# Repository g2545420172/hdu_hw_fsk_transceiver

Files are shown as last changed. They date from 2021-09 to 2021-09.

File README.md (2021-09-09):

# hdu_hw_fsk_transceiver
杭电2021秋季短学期 通信系统课程设计 基于 FSK 调制的 PC 机通信电路设计 
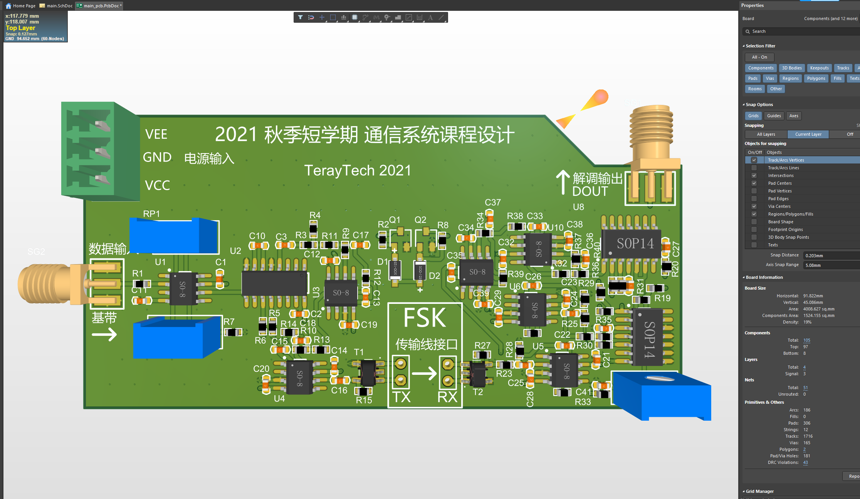
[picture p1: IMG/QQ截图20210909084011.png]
 
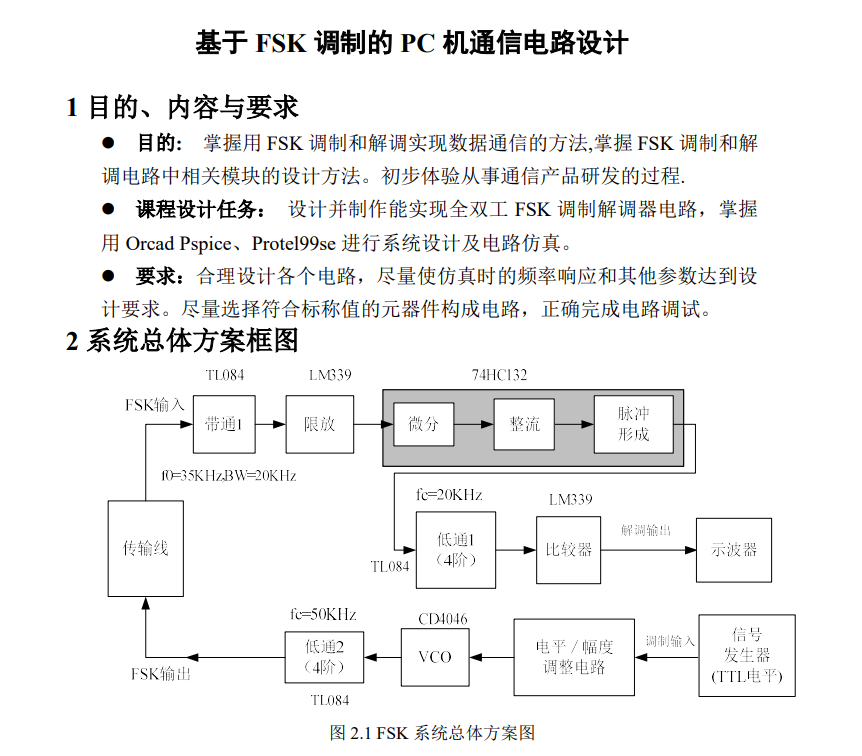
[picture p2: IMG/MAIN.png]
main
 
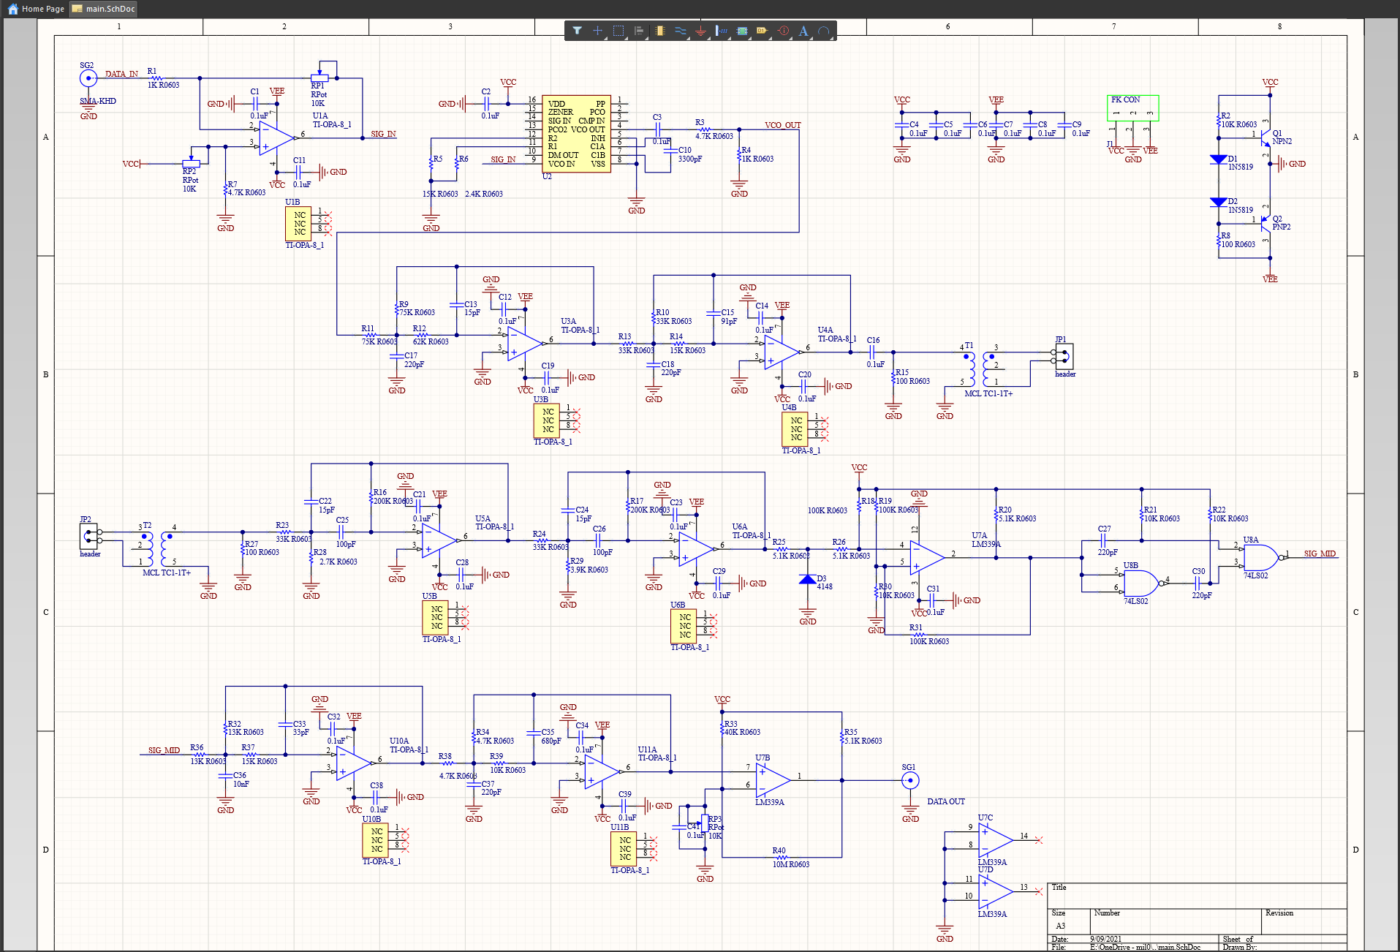
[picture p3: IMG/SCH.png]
sch
 
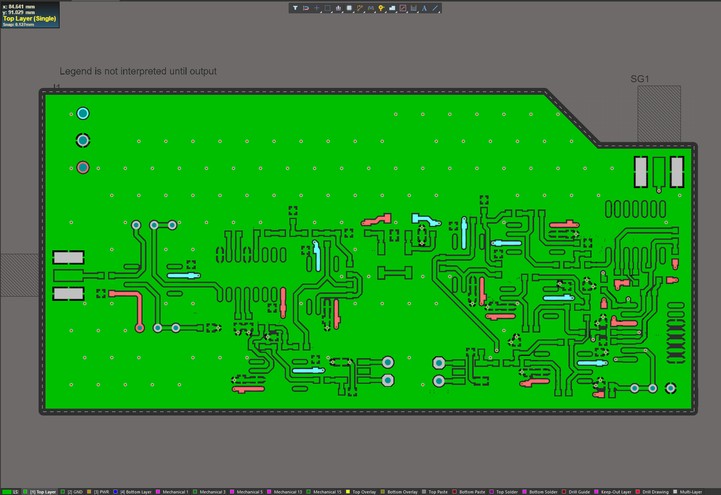
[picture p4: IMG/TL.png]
TL
 
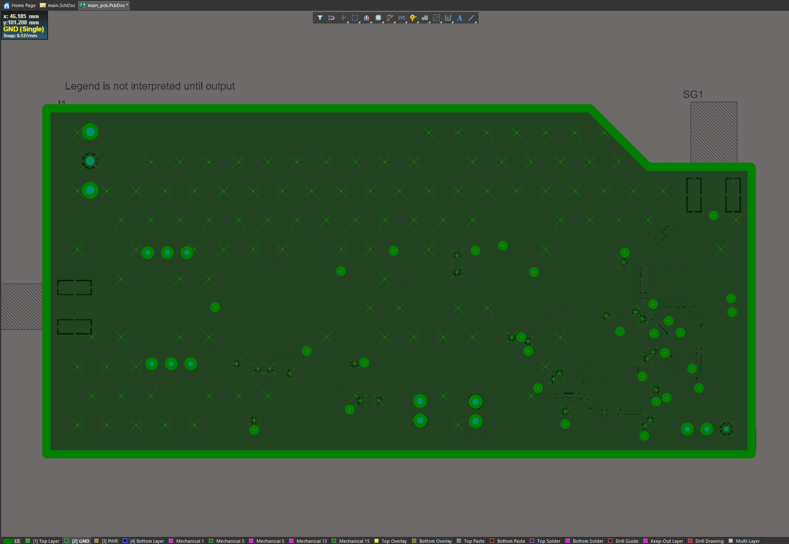
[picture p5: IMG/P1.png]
P1
 
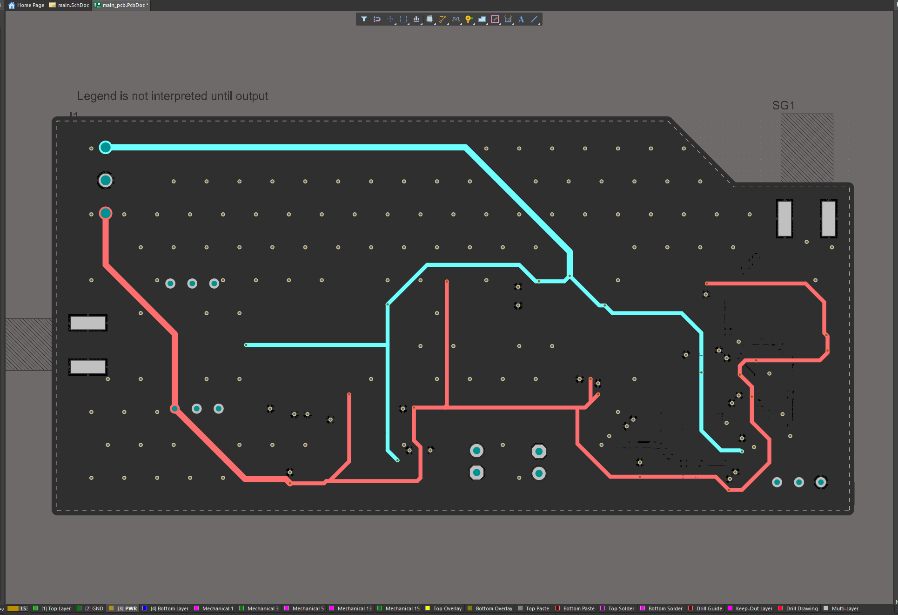
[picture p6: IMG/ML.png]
ML
 
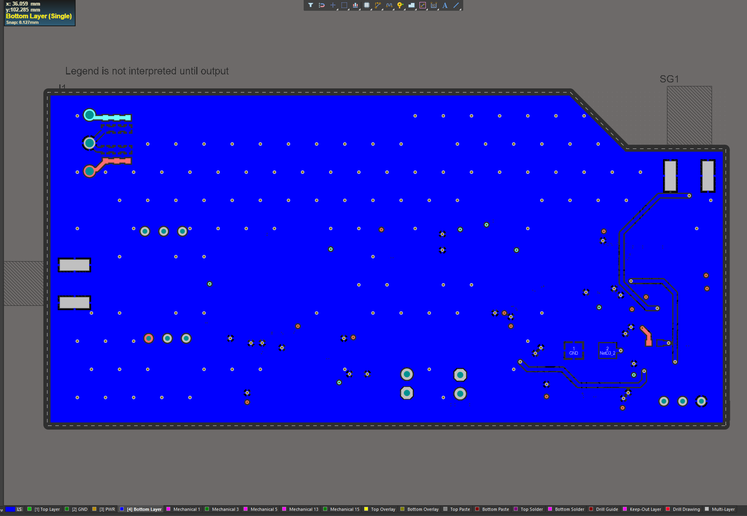
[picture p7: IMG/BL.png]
BL


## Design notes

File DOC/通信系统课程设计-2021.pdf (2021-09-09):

# 通信系统课程设计

## 栾慎吉 刘超

## 杭州电子科技大学

## 信息工程学院

2

3

## 基于 FSK 调制的 PC 机通信电路设计

## 1 目的、内容与要求

- 目的: 掌握用 FSK 调制和解调实现数据通信的方法,掌握 FSK 调制和解 调电路中相关模块的设计方法。初步体验从事通信产品研发的过程. 课程设计任务： 设计并制作能实现全双工 FSK 调制解调器电路，掌握

用 Orcad Pspice、Protel99se 进行系统设计及电路仿真。
- 要求：合理设计各个电路，尽量使仿真时的频率响应和其他参数达到设 计要求。尽量选择符合标称值的元器件构成电路，正确完成电路调试。

## 2 系统总体方案框图

图 2.1 FSK 系统总体方案图
- 信号调制过程如下：
调制数据由信号发生器产生（电平为 TTL，波特率不超过 9600Baud），送入 电平/幅度调整电路完成电平的变换，再经过锁相环（CD4046）,产生两个频率信 号分别为 30kHz 和 40kHz（发“1”时产生 30kHz 方波，发“0”时产生 40kHz 方波）， 再经过低通滤波器 2，变成平滑的正弦波，最后通过线圈实现单端到差分信号的 转换。
- 信号的解调过程如下：
首先经过带通滤波器 1，滤除带外噪声，实现信号的提取。在本设计中 FSK 信号的解调方式是过零检测法。所以还要经过比较器使正弦信号变成方波，再经 过微分、整流电路和低通滤波器 1 实现信号的解调，最后经过比较器使解调信号 成为 TTL 电平。在示波器上会看到接收数据和发送数据是一致的。
- 各主要电路模块作用：

4

电平/幅度调整电路：完成 TTL 电平到 VCO 控制电压的调整； VCO 电路：在控制电压作用下，产生 30KHz 和 40KHz 方波； 低通 2：把 30KHz、40KHz 方波滤成正弦波； 线圈：完成单端信号和差分信号的相互转换；
带通 1：对带外信号抑制，完成带内信号的提取；
限放电路：正弦波整形成方波，同时保留了过零点的信息； 微分、整流、脉冲形成电路：完成信号过零点的提取；
低通 1：提取基带信号，实现初步解调；
比较器：把初步解调后的信号转换成 TTL 电平；

## 3 系统设计技术要求

(1)FSK 解调方案：过零检测法
(2)信道复用方式：频分复用，全双工通信
(3)频率分配：f=35±5KHz， "1"--30KHz, "0"--40KHz (4)系统工作最高码元速率：RB=9600Baud
(5)线路阻抗：100 欧姆
(6)信号接收灵敏度：优于 10mv
(7)信号发送电平：1Vpp

图 3.1 FSK 信号的频谱

## 4 主要器件型号的选择及功能

74HC132：四 2 输入与非施密特触发器（用作过零检测电路） LM339：4 比较器（用作限放和比较器）
CD4046：COMS 锁相环（用作 VCO）
TL084：运算放大器（用作滤波器和电平／幅度调整电路用）

## 5 系统中各种滤波器设计要求

(1)带通 1 滤波器设计指标：
通带：26KHz-46KHz，通带波动 3dB；
阻带截止频率：fc＝75KHz 时，要求衰减大于 10dB；

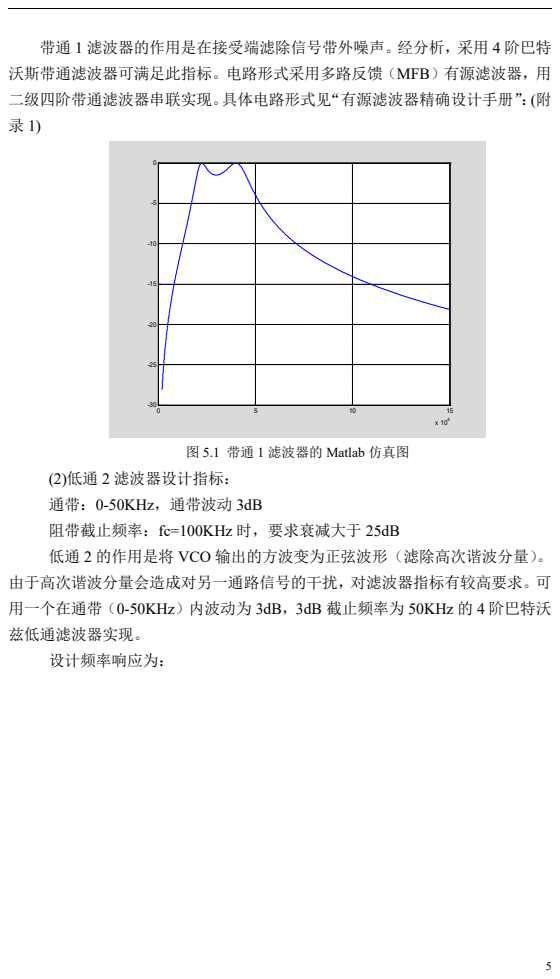
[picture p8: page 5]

带通 1 滤波器的作用是在接受端滤除信号带外噪声。经分析，采用 4 阶巴特
沃斯带通滤波器可满足此指标。电路形式采用多路反馈（MFB）有源滤波器，用
二级四阶带通滤波器串联实现。具体电路形式见“有源滤波器精确设计手册”：(附

图 5.1 带通 1 滤波器的 Matlab 仿真图

(2)低通 2 滤波器设计指标：
通带：0-50KHz，通带波动 3dB
阻带截止频率：fc=100KHz 时，要求衰减大于 25dB
低通 2 的作用是将 VCO 输出的方波变为正弦波形（滤除高次谐波分量）。
由于高次谐波分量会造成对另一通路信号的干扰，对滤波器指标有较高要求。可
用一个在通带（0-50KHz）内波动为 3dB，3dB 截止频率为 50KHz 的 4 阶巴特沃
兹低通滤波器实现。
设计频率响应为：

6

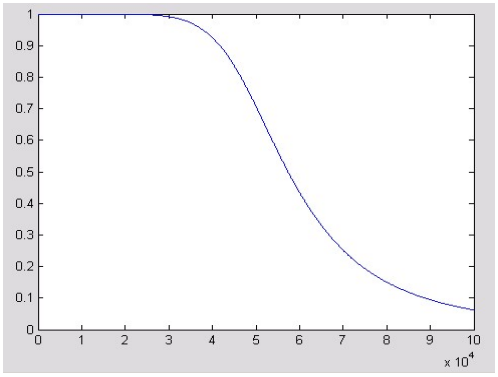
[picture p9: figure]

图 5.2 低通 2 滤波器的 Matlab 仿真图 (3)低通 1 指标：
通带：0-20KHz，通带波动 3dB；
阻带截止频率：fc＝30KHz 时，要求衰减大于 10dB；

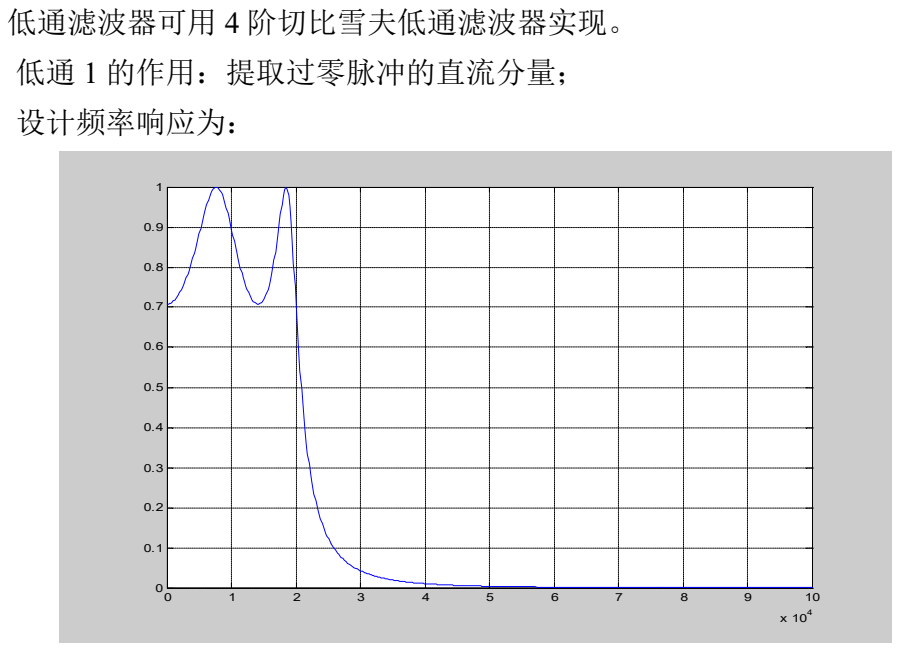
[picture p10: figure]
低通滤波器可用 4 阶切比雪夫低通滤波器实现。; 低通 1 的作用：提取过零脉冲的直流分量；; 设计频率响应为：

图 5.3 低通 1 滤波器的 Matlab 仿真图

## 6 系统中各部分模块参考电路

(1)带通 1(4 阶带通)-- 接收滤波器原理图及仿真图 要求通带：26KHz—46KHz，通带波动 3dB；阻带截止频率：fc＝75KHz 时，

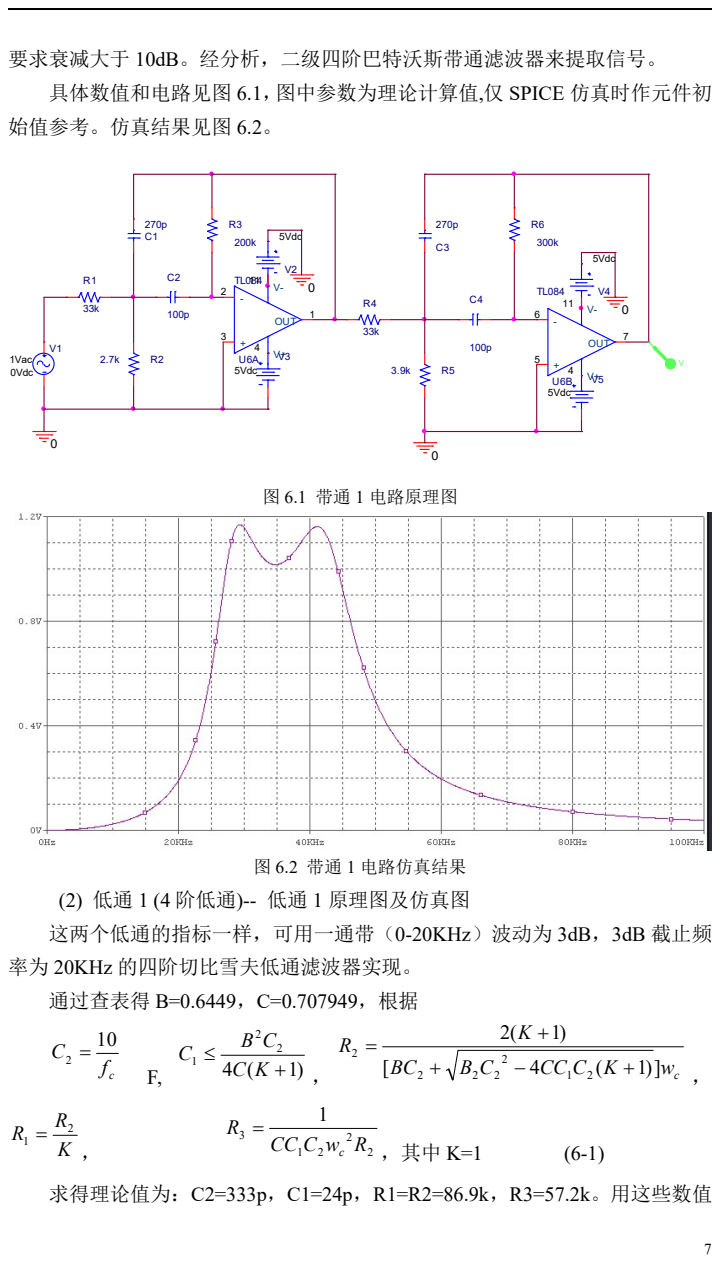
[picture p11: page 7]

要求衰减大于 10dB。经分析，二级四阶巴特沃斯带通滤波器来提取信号。
具体数值和电路见图 6.1，图中参数为理论计算值,仅 SPICE 仿真时作元件初
始值参考。仿真结果见图 6.2。 R1

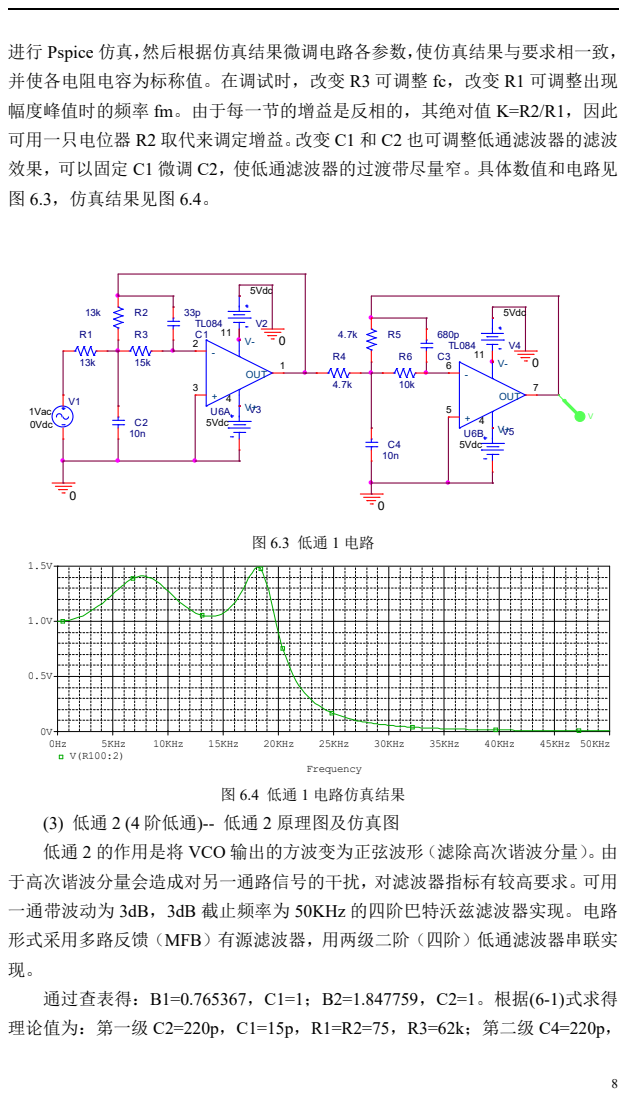
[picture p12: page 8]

进行 Pspice 仿真，然后根据仿真结果微调电路各参数，使仿真结果与要求相一致，
并使各电阻电容为标称值。在调试时，改变 R3 可调整 fc，改变 R1 可调整出现
幅度峰值时的频率 fm。由于每一节的增益是反相的，其绝对值 K=R2/R1，因此
可用一只电位器 R2 取代来调定增益。改变 C1 和 C2 也可调整低通滤波器的滤波
效果，可以固定 C1 微调 C2，使低通滤波器的过渡带尽量窄。具体数值和电路见
图 6.3，仿真结果见图 6.4。 R1

(3) 低通 2 (4 阶低通)-- 低通 2 原理图及仿真图
低通 2 的作用是将 VCO 输出的方波变为正弦波形（滤除高次谐波分量）。由
于高次谐波分量会造成对另一通路信号的干扰，对滤波器指标有较高要求。可用
一通带波动为 3dB，3dB 截止频率为 50KHz 的四阶巴特沃兹滤波器实现。电路
形式采用多路反馈（MFB）有源滤波器，用两级二阶（四阶）低通滤波器串联实
通过查表得：B1=0.765367，C1=1；B2=1.847759，C2=1。根据(6-1)式求得
理论值为：第一级 C2=220p，C1=15p，R1=R2=75，R3=62k；第二级 C4=220p，

6.6。 V1

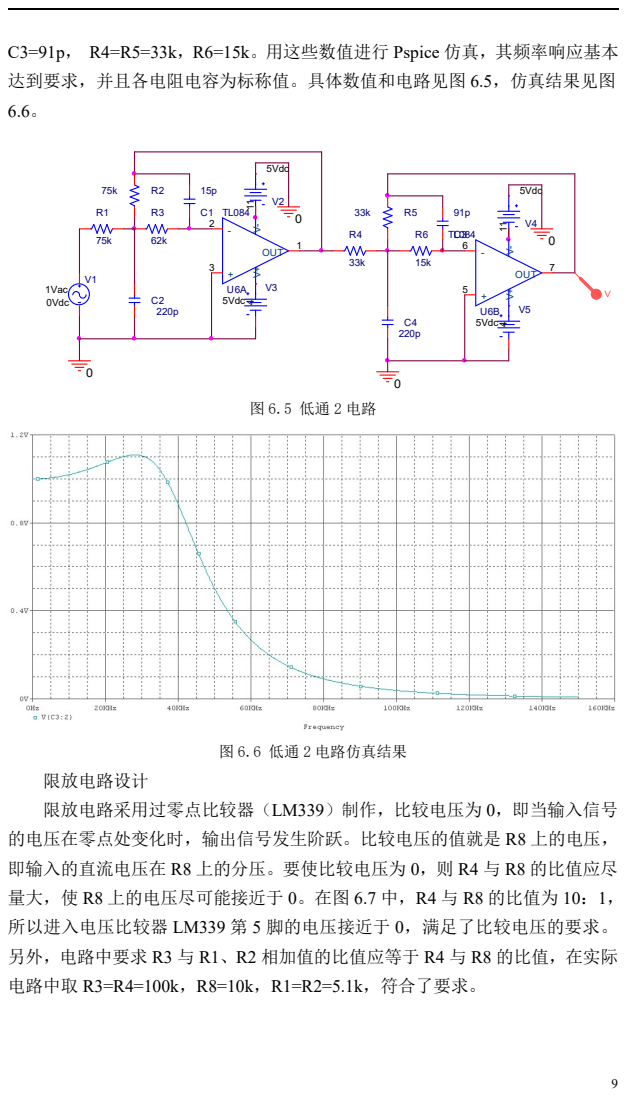
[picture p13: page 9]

C3=91p， R4=R5=33k，R6=15k。用这些数值进行 Pspice 仿真，其频率响应基本
达到要求，并且各电阻电容为标称值。具体数值和电路见图 6.5，仿真结果见图

限放电路设计
限放电路采用过零点比较器（LM339）制作，比较电压为 0，即当输入信号
的电压在零点处变化时，输出信号发生阶跃。比较电压的值就是 R8 上的电压，
即输入的直流电压在 R8 上的分压。要使比较电压为 0，则 R4 与 R8 的比值应尽
量大，使 R8 上的电压尽可能接近于 0。在图 6.7 中，R4 与 R8 的比值为 10：1，
所以进入电压比较器 LM339 第 5 脚的电压接近于 0，满足了比较电压的要求。
另外，电路中要求 R3 与 R1、R2 相加值的比值应等于 R4 与 R8 的比值，在实际
电路中取 R3=R4=100k，R8=10k，R1=R2=5.1k，符合了要求。

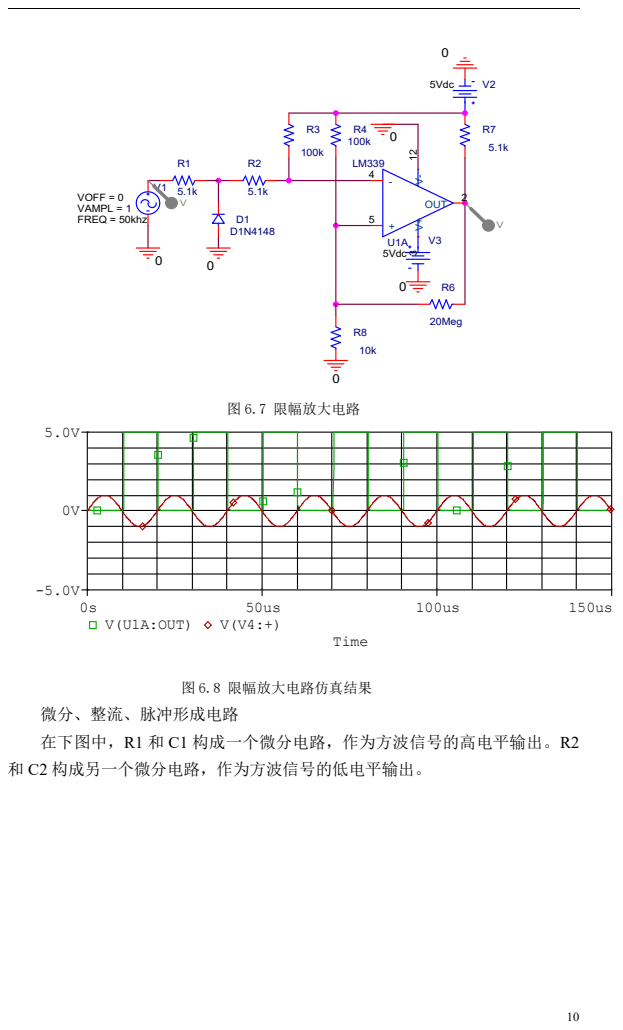
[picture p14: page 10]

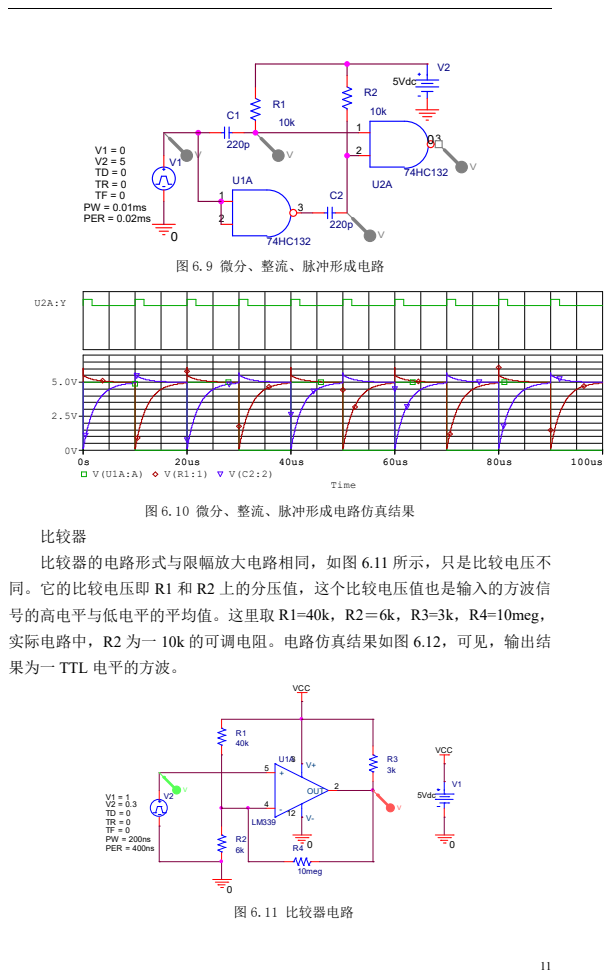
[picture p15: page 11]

比较器
比较器的电路形式与限幅放大电路相同，如图 6.11 所示，只是比较电压不
同。它的比较电压即 R1 和 R2 上的分压值，这个比较电压值也是输入的方波信
号的高电平与低电平的平均值。这里取 R1=40k，R2＝6k，R3=3k，R4=10meg，
实际电路中，R2 为一 10k 的可调电阻。电路仿真结果如图 6.12，可见，输出结
果为一 TTL 电平的方波。

12

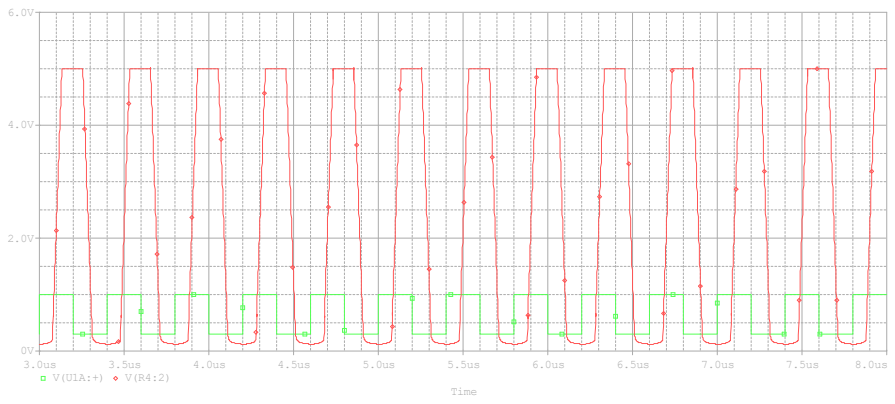
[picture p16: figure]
Time

图 6.12 比较器电路仿真结果
电平/幅度调整电路
电平/幅度调整电路如图 6.13，根据 VCO 电路的实际调试结果得出与各频率 相对应的输入电压即电平/幅度调整电路的输出电压，并据此进行 Pspice 仿真。

1

1 1

1

1
0 1

( )
R

V R Rf ViRf Rf
R

Vi V
V V

在实际电路中 R1＝75k，Rf 是一阻值为 10k 的可调电阻，所以调整 Rf 可以 改变输出 Vo 的大小，若减小 Rf，则 Vo 增大；若增大 Rf，则 Vo 减小，据此进 行电路调整，使输出符合要求。而电阻 R2、R3 的分压值决定了输出 Vo 的中心 电平，在实际电路中，R2 为一阻值为 10k 的可调电阻，改变 R2，可以调整输出 Vo 的中心电平，使输出满足要求。
中心频率 fo=35kHz 时对应的电压为 1.9V，f=30kHz 对应的电压为 1.74V， f=40kHz 对应的电压为 2.08V，这就是电路输出的直流电压分量和方波信号的电

压范围。其中直流电压就是 TL084 第 3 脚输入的电压 V1，即 5V 的电源电压在 R3 上的分压。按比例计算得 R2、R3 的值。输出的方波信号的电压 Vo 由 R2、 Rf 来调节，使之高低电平分别为 1.74V 和 2.08V，在 Pspice 仿真中使用参数扫描，

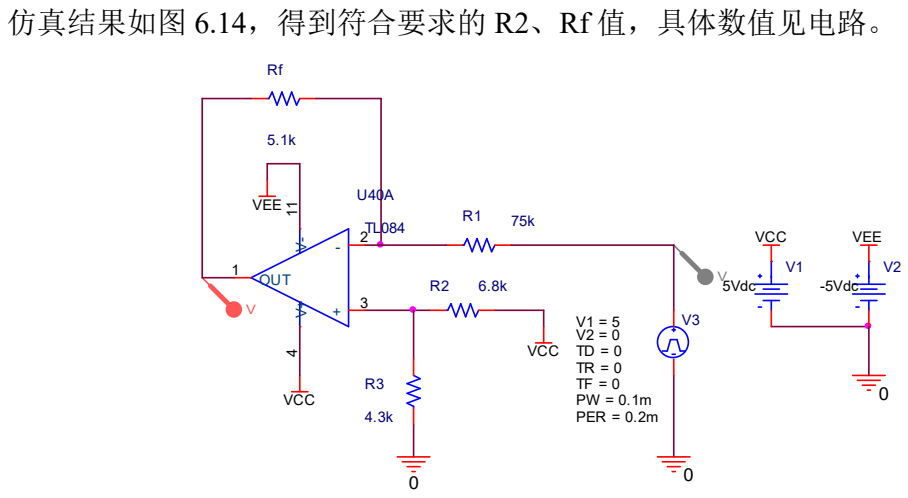
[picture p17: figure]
仿真结果如图 6.14，得到符合要求的 R2、Rf 值，具体数值见电路。; Rf 5.1kVCC; 75kVCC; 5Vdc 0V3 TD = 0 TF = 0 PW = 0.1m; PER = 0.2m; -5Vdc R3; VCC; 6.8k VEE; VEE U40A; - V⁺ V⁻ OUT

13

图 6.13 电平/幅度调整电路

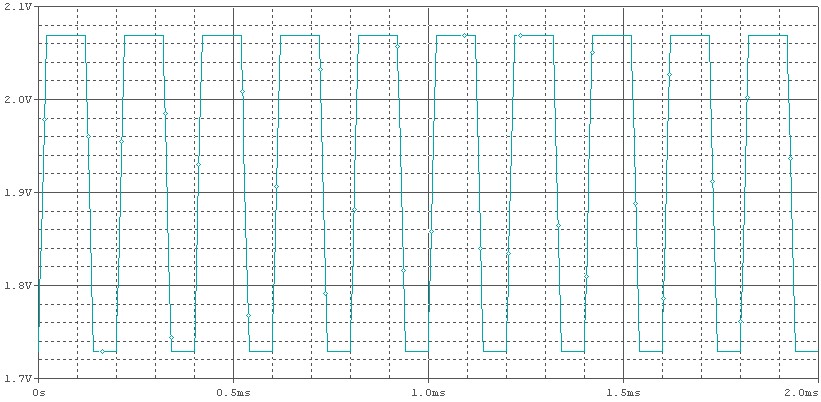
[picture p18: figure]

图 6.14 电平/幅度调整电路仿真结果

### - VCO 电路

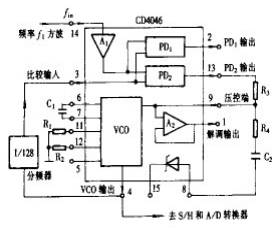
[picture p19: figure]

图 6.15 VCO 电路管脚图
CD4046 锁相环结构如图 6.15，采用的是 RC 型压控振荡器，必须外接电容 C1（接在 6 脚与 7 脚之间）和电阻 R1 作为充放电元件。由于 PLL 对跟踪的输入 信号的频率宽度有要求，所以还需要外接电阻 R2。由于 VCO 是一个电流控制振 荡器，对定时电容 C1 的充电电流与从 9 脚输入的控制电压成正比，使 VCO 的 振荡频率亦正比于该控制电压。当 VCO 控制电压为 0 时，其输出频率最低；当 输入控制电压等于电源电压 VDD 时，输出频率则线性地增大到最高输出频率。 VCO 的工作频率是由 9 管脚上的电压以及 6 和 7 管脚上的电容和 R1、R2 的阻 值确定的。R1 确定最高频率，R2 确定最低工作频率。由于它的充电和放电都由 同一个电容 C1 完成，所以输出的波形是对称方波。
利用 CD4046 的 VCO 可组成一个 V—F（电压—频率）转换器，当其 9 脚输 入的电压从 Vss 变化到 Vdd 时，从 4 脚输出的振荡方波信号的频率成线性变化。

14

变化的频率范围依外接 C1、R1 和 R2 值的不同而异。在 Fmax 和 Fmin 的比值较 小的情况下，R2/R1 可看做与 Fmax/Fmin 成线性关系。
当 Fmin=30kHz，Fmax=40kHz 时，计算得 R1=2.4k，R2=15k，C1=3300p， 在实际的电路板上进行调试，发现中心频率 fo=35kHz 时对应的电压为 1.9V， f=30kHz 对应的电压为 1.74V，f=40kHz 对应的电压为 2.08V，这就是电平/幅度

调整电路所输出的直流电压和方波信号的电压范围。

## 7 系统中电路原理图及 PCB 说明

本系统的电路原理图如图 7.1 所示，由以下几部分组成：电源电路、FSK 调 制电路及 FSK 解调电路组成。相应的 PCB 如图 7.2，该版图的尺寸是 7cm×8cm， 为双面版。版图的尺寸应尽量小，以减少制版费用。按照这个尺寸在 KeepOutLayer 层先画出 PCB 的边界，然后进行元器件的布局、调整，合理的布局能够带来良 好的布线效果。

15

16

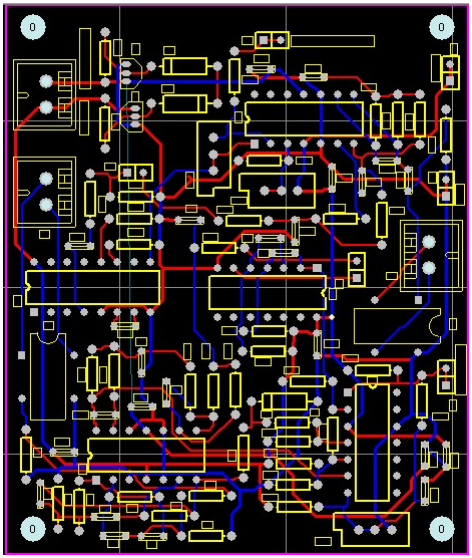
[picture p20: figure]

图 7.2 系统 PCB 版图

17

该设计的材料清单（一份）如下：
元件值 | 名称 | 封装
0.1u(8 个) | C19 | capnew
0.1u | C18 | capnew
0.1u | C20 | capnew
0.1u | C22 | capnew
0.1u | C21 | capnew
0.1u | C17 | capnew
0.1u | C16 | capnew
0.1u | C14 | capnew
1k | R41 | AXIAL0.3
2.4k | R42 | AXIAL0.3
2.7k | R7 | AXIAL0.3
3.9k | R9 | AXIAL0.3
3k | R35 | AXIAL0.3
4.7k(4 个) | R28 | AXIAL0.3
4.7k | R31 | AXIAL0.3
4.7k | R29 | AXIAL0.3
4.7k | R30 | AXIAL0.3
5.1k(3 个) | R13 | AXIAL0.3
5.1k | R11 | AXIAL0.3
5.1k | R12 | AXIAL0.3
10Meg | R34 | AXIAL0.3
10k(6 个) | R19 | AXIAL0.3
10k | R18 | AXIAL0.3
10k | R16 | AXIAL0.3
10k | R17 | AXIAL0.3
10k | R20 | AXIAL0.3
10k | R21 | AXIAL0.3
10k(可调变阻器，3 个) | R40 | VR5
10k | R39 | VR5
10k | R32 | VR5
10n(2 个) | C10 | capnew
10n | C11 | capnew
13k(2 个) | R23 | AXIAL0.3
13k | R24 | AXIAL0.3
15k(3 个) | R27 | AXIAL0.3
15k | R25 | AXIAL0.3
15k | R26 | AXIAL0.3
15p | C23 | capnew
20Meg | R22 | AXIAL0.3
33k(4 个) | R3 | AXIAL0.3
33k | R6 | AXIAL0.3
33k | R4 | AXIAL0.3
33k | R5 | AXIAL0.3
33p | C12 | capnew
40k | R33 | AXIAL0.3
62k | R43 | AXIAL0.3

18

75k(3 个) | R36 | AXIAL0.3
75k | R37 | AXIAL0.3
75k | R38 | AXIAL0.3
91p | C24 | capnew
100(2 个) | R1 | AXIAL0.3
100 | R2 | AXIAL0.3
100k(2 个) | R15 | AXIAL0.3
100k | R14 | AXIAL0.3
100p(3 个) | C4 | capnew
100p | C3 | capnew
100p | C5 | capnew
200k | R8 | AXIAL0.3
220p(4 个) | C8 | capnew
220p | C9 | capnew
220p | C6 | capnew
220p | C7 | capnew
270p(2 个) | C1 | capnew
270p | C2 | capnew
300k | R10 | AXIAL0.3
680p | C13 | capnew
3300p | C15 | capnew
9012 | Q2 | TO-92B
9013 | Q1 | TO-92B
DIODE | D2 | DIODE0.4
DIODE | D1 | DIODE0.4
DIODE | D3 | DIODE0.4
TRANS1 | T1 | t
TRANS1 | T2 | t
芯片 | 总个数
TL084 | 2 只
LM339 | 1 只
74HC132 | 1 只
CD4046 | 1 只
插件名称及个数 | 封装
J1、J2、J3(共 3 只) | MT6CON2 V
U5 | DIP16
U1、U2、U3 和 U4(共 4 只) | DIP14
s1、s2、s3、s4、s5 和 s6 (共 6 只) | SIP2

19

### 实验报告要求

一、 目的、内容与要求

二、 总体方案设计

三、 单元电路设计原理、计算机仿真分析

四、 总结(仿真遇到的问题、解决方法及心得体会)

20

# OrCAD/PSPICE 使用简介

## 杭州电子科技大学

## 信息工程学院

2021 年

# Orcad/Pspice 电路分析步骤

## 1. 启动 Capture CIS：

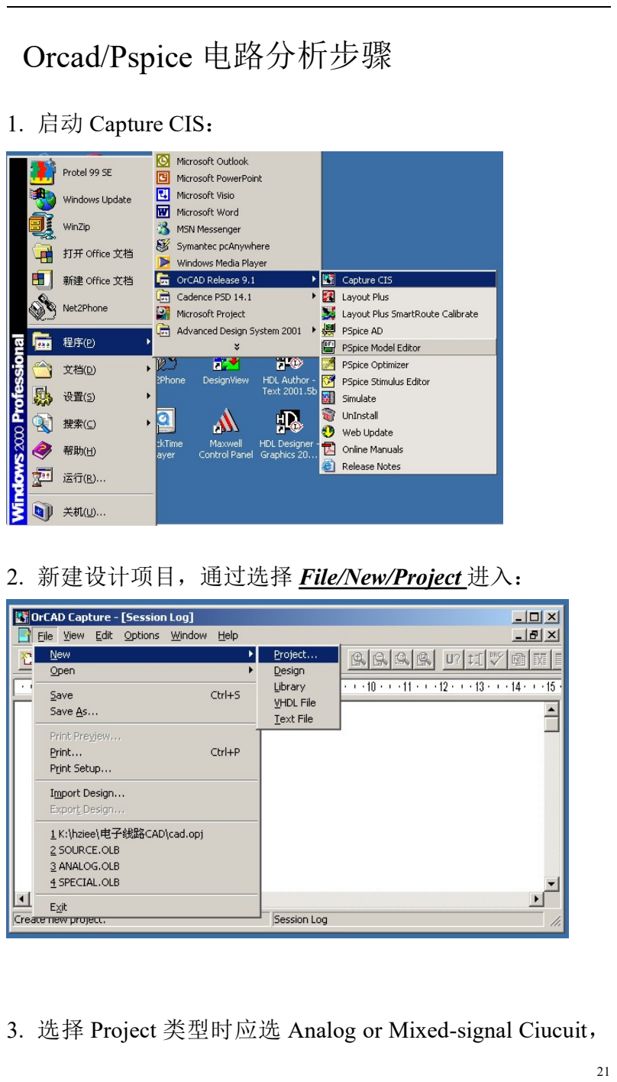
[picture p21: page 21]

21

## 2. 新建设计项目，通过选择 File/New/Project 进入：

## 3. 选择 Project 类型时应选 Analog or Mixed-signal Ciucuit，

## 并确定文件名和存盘路径：

22

## 4. 选择必要的元器件库（以后也可添加）：

## 5. 选完成进入设计窗口：

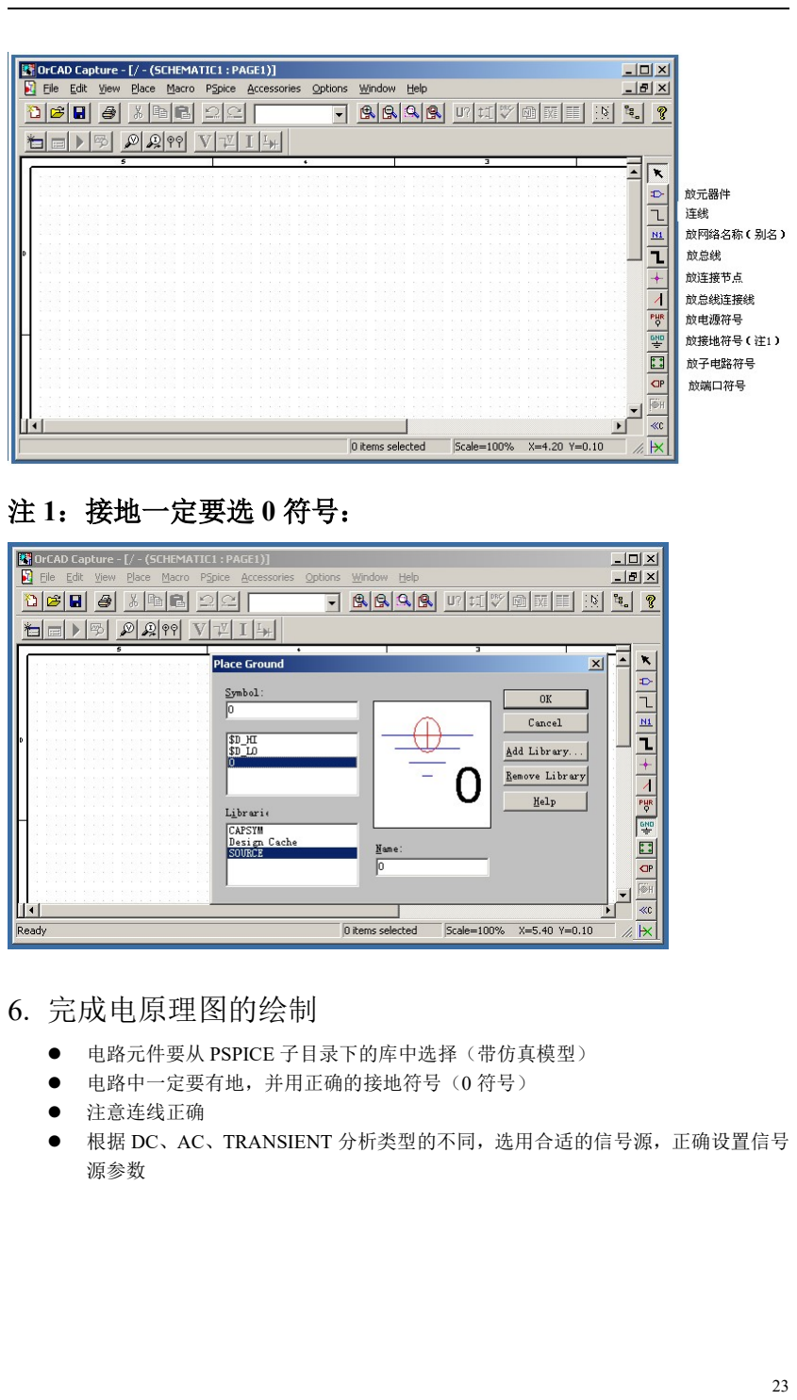
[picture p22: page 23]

23

### 注 1：接地一定要选 0 符号：

## 6. 完成电原理图的绘制

- 电路元件要从 PSPICE 子目录下的库中选择（带仿真模型）
- 电路中一定要有地，并用正确的接地符号（0 符号）
- 注意连线正确
- 根据 DC、AC、TRANSIENT 分析类型的不同，选用合适的信号源，正确设置信号 源参数

24

## 7. 在PSPICE菜单下新建或编辑 Simulation Profile(模拟模式

## 文件) 文件：

## 8. 设置 Simulation Profile 文件参数

25

- 选择分析类型：
- 对选定的分析类型设置正确的参数
对瞬态分析要选择合适的分析时间和最大步长（Maximun step）。对脉冲、正弦等 具有周期性质的信号而言，最大分析步长可取周期的 1/10-1/5。 AC 分析可附带进行噪声分析，Time Domain 分析可附带进行傅里叶分析（谐波失

真分析）

## 9. 选 PSPICE 菜单中的 RUN 或快捷工具条进行电路分析

## 10.观测模拟结果

26

- 增加曲线：Trace/Add Trace
- 显示光标、极值等搜索功能
- 可将曲线拷入剪贴板中，供嵌入 word 等文档使用

27

# Orcad/Pspice 电路分析上机练习题

## 练习题

### 1. 二极管伏安特性分析（DC 扫描分析，单参数扫描）

0

V1
0.5Vdc

I D1

D1N4148

注：二极管在 Diode 库中，电压源在 SOURCE 库中
参考参数设置：

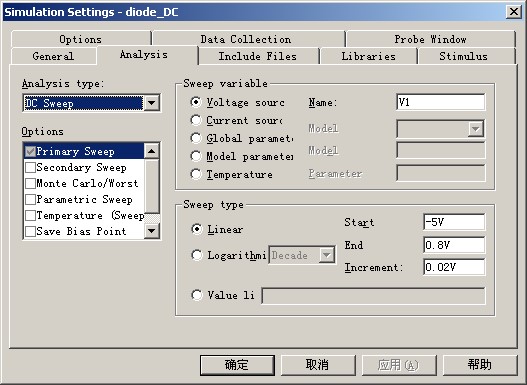
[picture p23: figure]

参考分析结果：

28

### 2. 三极管共射输出特性曲线分析（DC 扫描分析，双扫描参数）

I1

1mAdc

Q2

Q2N2220

0

V1
12Vdc

注：三极管在 Bipolar 库中，电压源、电流源在 SOURCE 库中

### 参考参数设置：

主扫描参数：

参变量参数设置：

分析结果：

29

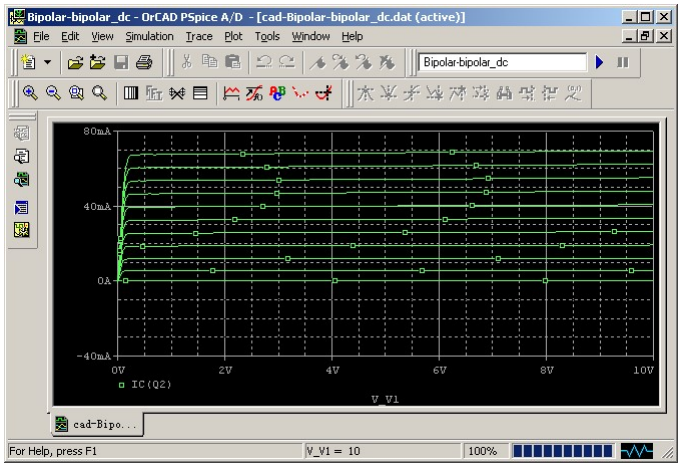
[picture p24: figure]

### 3. 如下电路，试计如所示的电路在（0℃）到 40℃时的直流工作点 IBQ、VBEQ、ICQ 随温

度升变化时的工作点变化曲线。

提示：
参数设置如下：

0

0

VCC

R2
4.6K

12Vdc V1 VCC
R1
73K

Q1

Q2N2222

R3
2k

30

## 练习题（AC 分析）

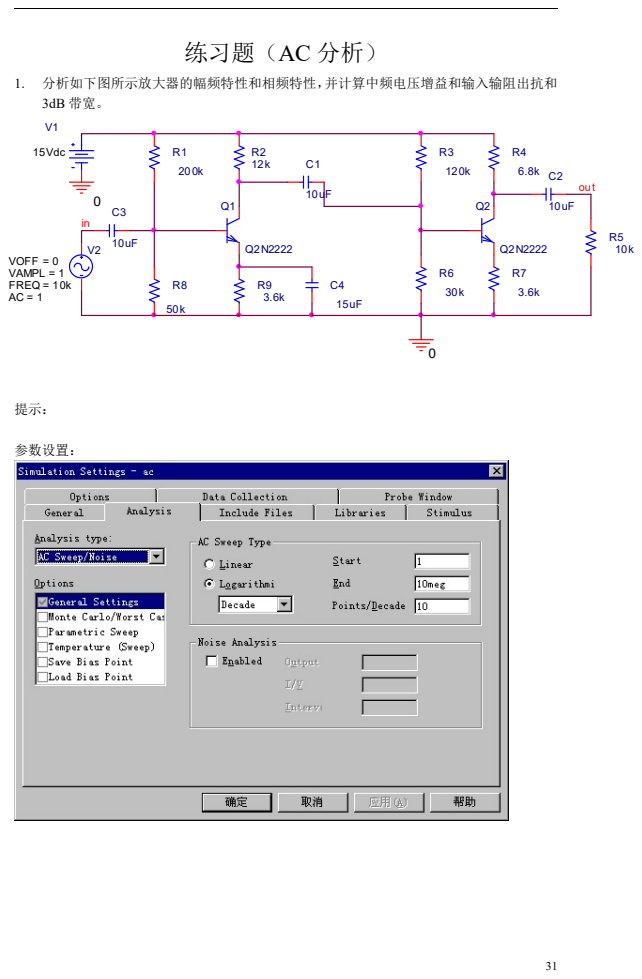
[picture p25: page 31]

32

模拟结果：
从图中可见，中频增益为 45.7dB, 3dB 带宽为 1.73MHz.

从上图可见，中频增益为 45.7dB, 3dB 带宽为 1.73MHz.

从上图可见，中频的输入阻抗为 6Kohm.

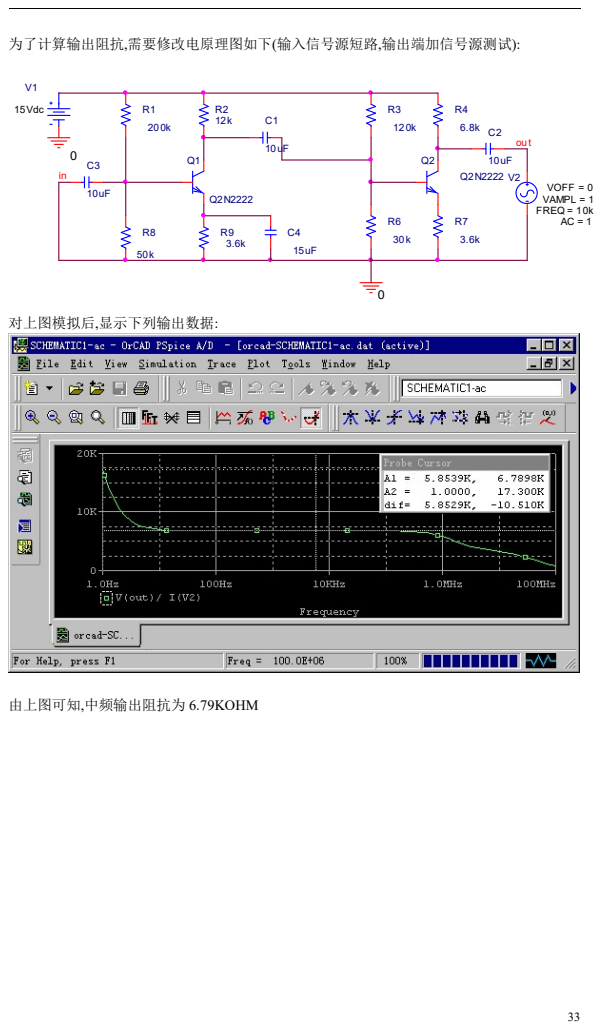
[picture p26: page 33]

为了计算输出阻抗,需要修改电原理图如下(输入信号源短路,输出端加信号源测试):

34

### 2. 分析如下有源低通滤波器电路。扫描 R1 的值从 60K 到 100K 时（每 10K 扫描一点），

滤波器频率特性的变化。

PARAM ET ERS:
Rv al = 91k

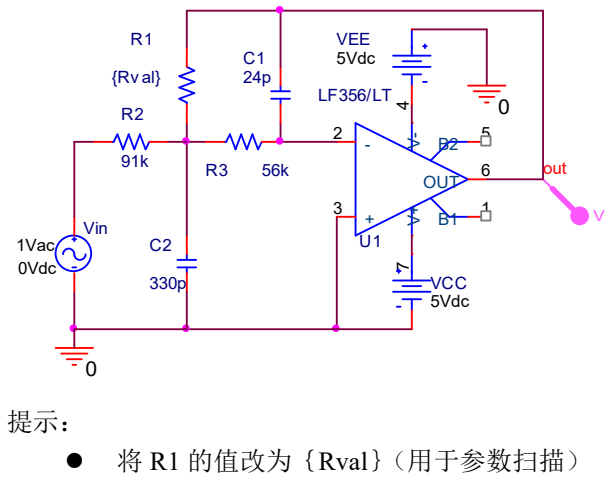
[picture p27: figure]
- V⁺ V⁻ OUT B2; VEE 5Vdc; Vin; 1Vac 0Vdc; out; VCC 5Vdc; 提示： 将 R1 的值改为｛Rval｝（用于参数扫描）

- 放置 PARAMETERS 符号，在 SPECIAL 库中，选 PARAM 元件

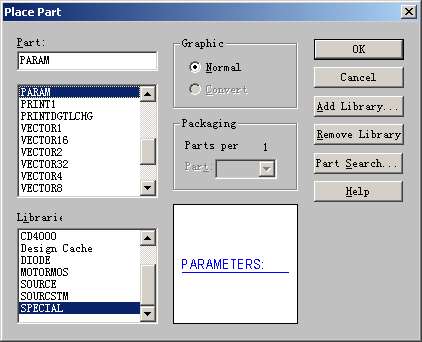
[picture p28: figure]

- 双击电原理图中的 PARAM 元件，编辑属性参数：

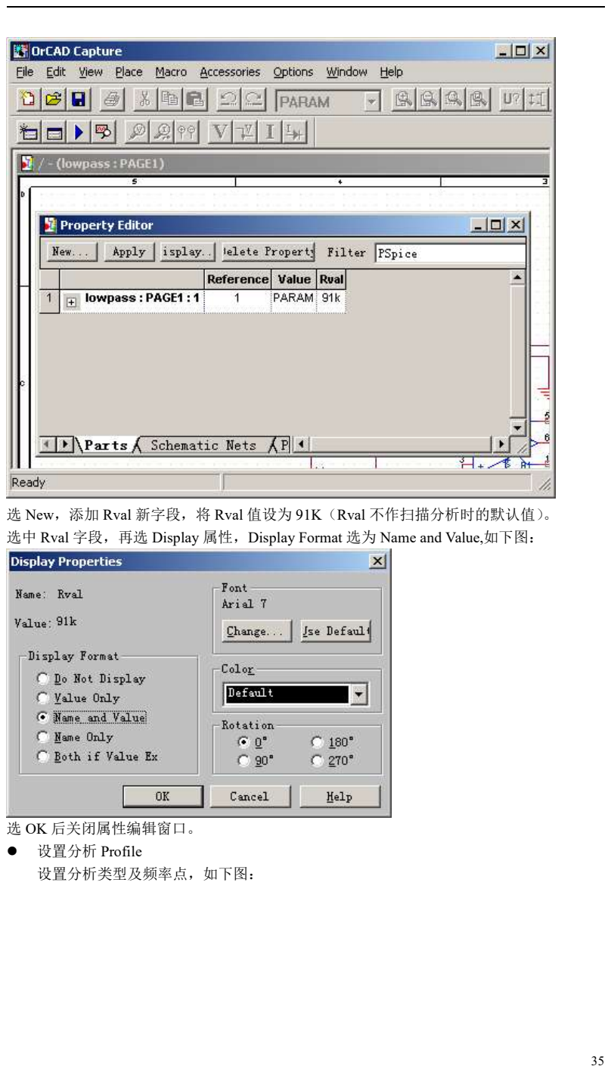
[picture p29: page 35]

35

选 New，添加 Rval 新字段，将 Rval 值设为 91K（Rval 不作扫描分析时的默认值）。 选中 Rval 字段，再选 Display 属性，Display Format 选为 Name and Value,如下图：

选 OK 后关闭属性编辑窗口。
- 设置分析 Profile
设置分析类型及频率点，如下图：

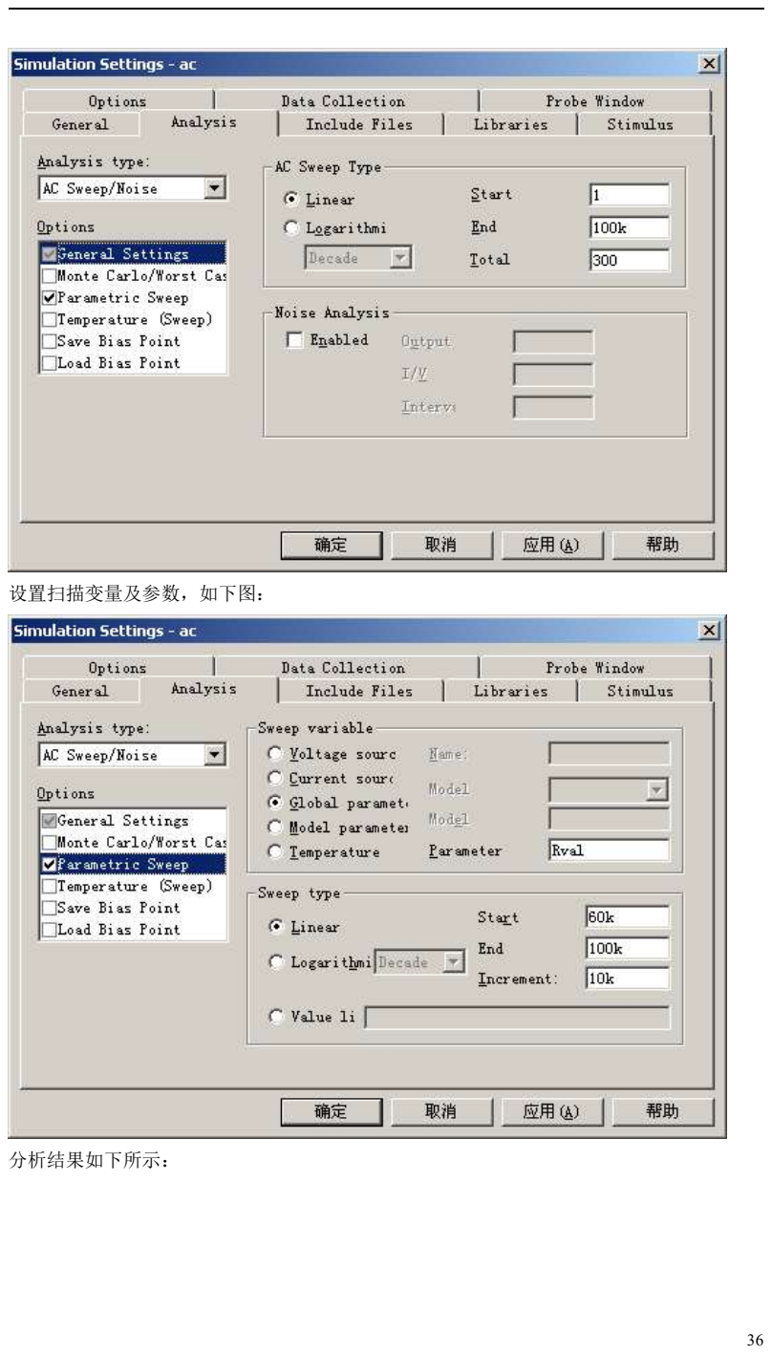
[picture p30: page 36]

36

设置扫描变量及参数，如下图：

分析结果如下所示：

37

### 3. 当改变两电感间的耦合系数时，分析对如下双调谐电路的选频特性的影响：

I1

0Adc

1Aac

out

0

R2

1k

C1

10p

L1

10uH

K K1
COUPLING = {CPLv al} K_Linear

L1 = L1
L2 = L2

C2

11p V R1

1k

L2

10uH

PARAM ET ERS:
CPLv al = 0.5

提示：
K 在库 ANALOG 中，
分析 Profile 设置如下：

38

参考结果：

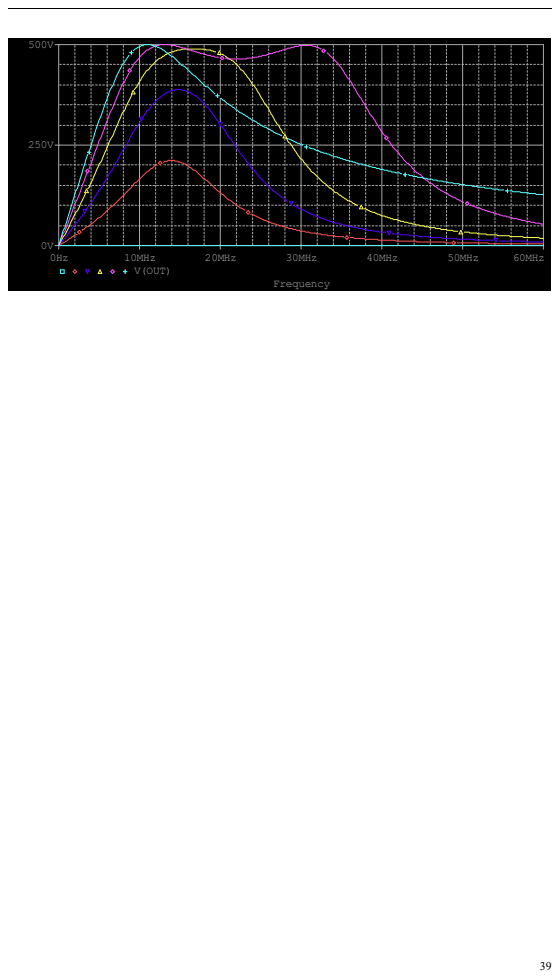
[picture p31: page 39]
Frequency; 10MHz; 20MHz; 30MHz; 40MHz; 50MHz; 60MHz; V(OUT)
